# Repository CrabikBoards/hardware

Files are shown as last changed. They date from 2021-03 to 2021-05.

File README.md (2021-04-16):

# crabik

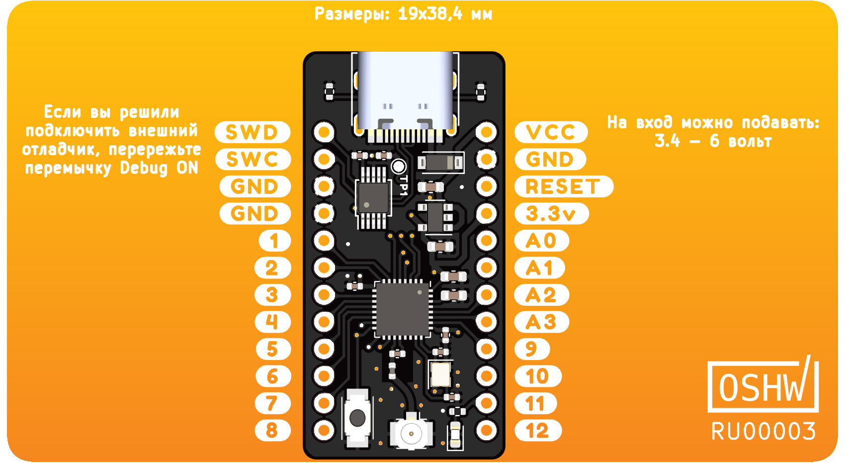
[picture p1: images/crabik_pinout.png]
crabik


Репозиторий с файлами дизайна платы для KiCad 5.1

| Вид сверху | Вид снизу |
|---|---|
| crabik_front | crabik_back |

## Описание

crabik это недорогая плата для изучения языка программирования [Rust](https://www.rust-lang.org/). Мозгом платы является микроконтроллер nRF52810. Плата имеет встроенный отладчик, основанный на CMSIS-DAP.

## Производство

Инструкция для заказа производства платы и монтажа на сервисе JLCPCB содержится в файле [PRODUCTION](PRODUCTION.md).

## Лицензия

Оборудование выпущено под лицензией CERN Open Hardware License v1.2. См. Файл [LICENSE](LICENSE) для получения дополнительной информации.

## Поддержка
Поддержите Амперку и оборудование с открытым исходным кодом, покупая продукты на [Amperka.ru](https://amperka.ru/)!

## Социальные сети Амперки

https://www.youtube.com/user/AmperkaRu

https://vk.com/amperkaru

https://www.instagram.com/amperkaru

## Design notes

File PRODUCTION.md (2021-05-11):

# Заказ производства

Загрузите дизайн из репозитория:
```
git clone git@github.com:CrabikBoards/hardware.git
```

В директории `production` находятся файлы BOM, позиций компонентов для монтажа, архив с GERBER файлами и файлами сверловки.

На сайте [jlcpcb.com](https://jlcpcb.com/) закажите печатные платы с монтажом.
Ниже показаны параметры заказа которые нужно выбрать, кол-во, цвет, толщина, и прочее выбирайте по своему желанию.

order settings 1

order settings 2

order settings 3

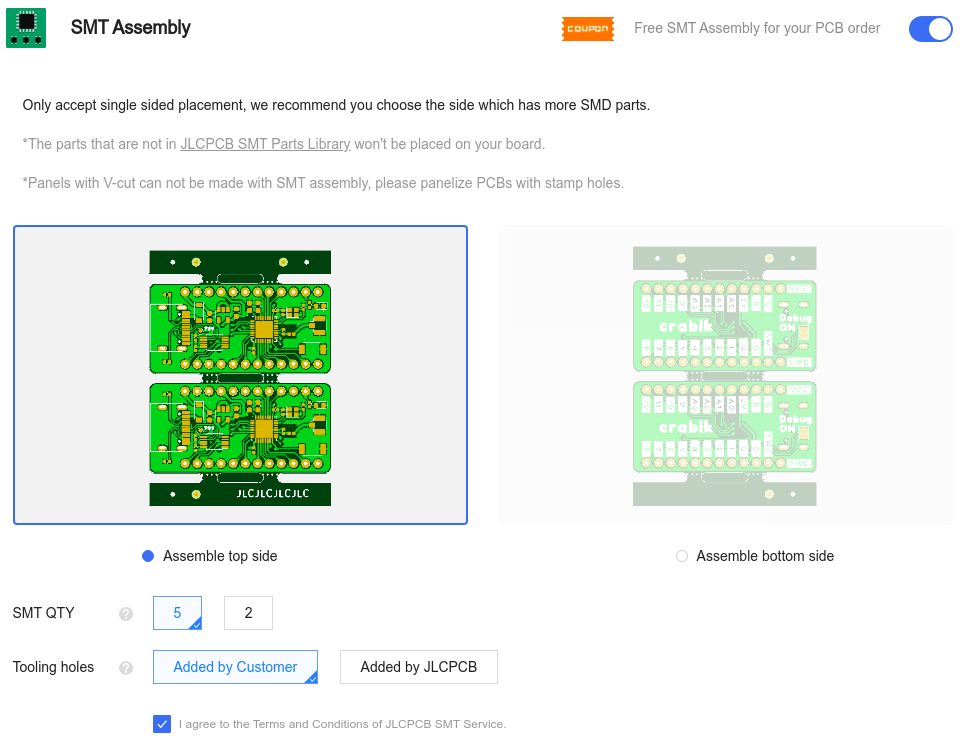
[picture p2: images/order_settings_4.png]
order settings 4


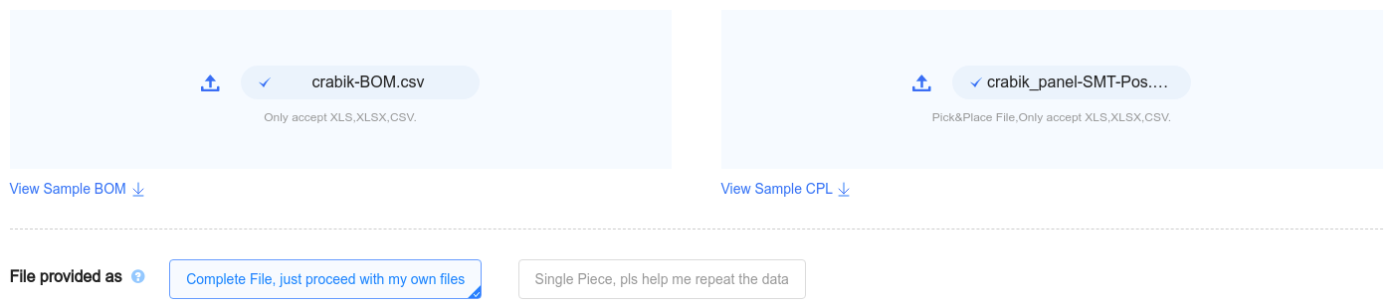
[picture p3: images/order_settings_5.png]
order settings 5


После получения и сборки платы, нужно прошить чип CH554 который выполняет роль CMSIS-DAP совместимого отладчика.

Установите Arduino IDE если она у вас не установлена и [добавте поддержку чипов CH55x](https://github.com/DeqingSun/ch55xduino#installation).

Загрузите Arduino проект из репозитория:
```
git clone git@github.com:CrabikBoards/debugger-firmware.git
```

Соедините контакт `TP1` с `VCC` через 20kOhm резистор, подключите плату к компьютеру и загрузите прошивку.

Все плата готова к работе!

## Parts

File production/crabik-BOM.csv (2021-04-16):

Comment | Designator | Footprint | LCSC Part #
U.FL-R-SMT-1 Generic connector, single row, 01x02, script generated (kicad-library-utils/schlib/autogen/connector/) | ANT1 | U.FL_Hirose_U.FL-R-SMT-1_Vertical | C88374
0.8pF Unpolarized capacitor, small symbol | C1 | C_0402_1005Metric | C326068
12pF Unpolarized capacitor, small symbol | C2,C3 | C_0402_1005Metric | C1547
100nF Unpolarized capacitor, small symbol | C4,C5,C9,C8 | C_0402_1005Metric | C1525
4.7uF Unpolarized capacitor, small symbol | C6 | C_0603_1608Metric | C8032
1uF Unpolarized capacitor, small symbol | C7,C11,C10 | C_0603_1608Metric | C1592
MBR0520 Schottky diode | D1 | D_SOD-123 | C475717
LED Light emitting diode | D2 | LED_0603_1608Metric | C2286
3.9nH Inductor | L1 | L_0402_1005Metric | C14033
USB-C USB 2.0-only Type-C Plug connector | P1 | TYPE-C16PIN | C393939
5.1K Resistor | R1,R2 | R_0402_1005Metric | C25905
1.5K Resistor | R3 | R_0402_1005Metric | C25867
Reset button Push button switch, generic, two pins | SW1 | TS-1088R-02526 | C455281
CH552E (or CH554E) | U1 | MSOP-10_3x3mm_P0.5mm | C111293
nRF52810-QCxx | U2 | QFN-32-1EP_5x5mm_P0.5mm_EP3.6x3.6mm | C519278
AP2112K-3.3 150mA low dropout linear regulator, wide input voltage range, 1.5V fixed positive output, SOT-23-5 | U3 | SOT-23-5 | C51118
32MHz Four pin crystal, GND on pins 2 and 4 | Y1 | Crystal_SMD_2016-4Pin_2.0x1.6mm | C254298

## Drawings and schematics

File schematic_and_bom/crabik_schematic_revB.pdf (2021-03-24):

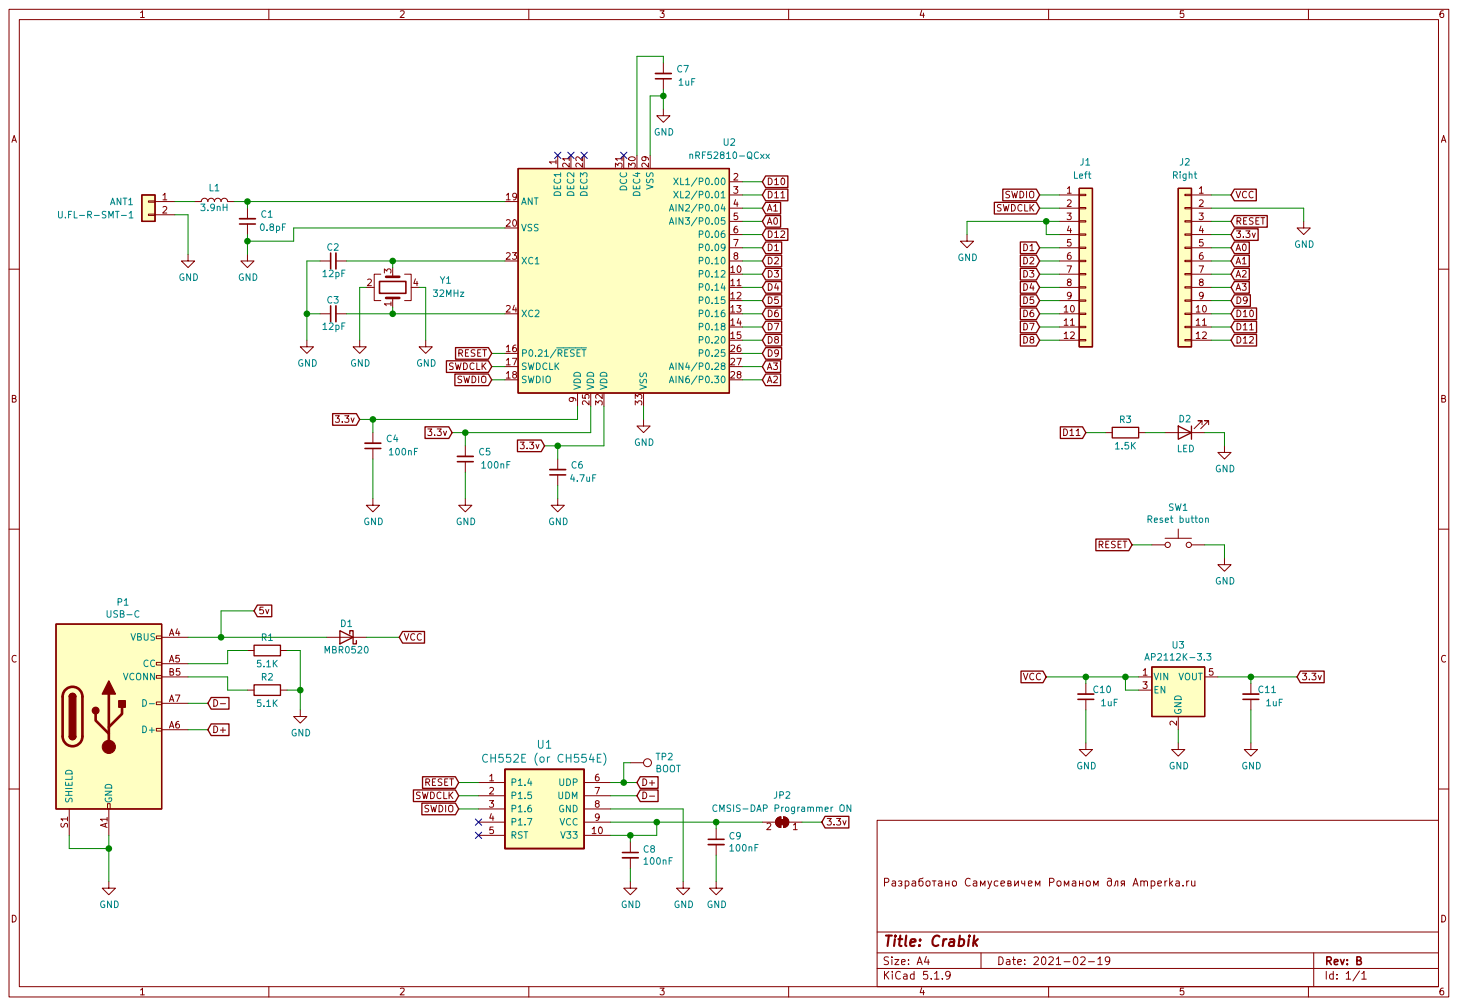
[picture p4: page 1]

1 P0.12 10 P0.14 11 P0.15 12 P0.16 13 P0.18 14 P0.20 15 P0.21/RESET 16 SWDCLK 17 SWDIO 18 ANT 19 XL1/P0.00 2 VSS 20 DEC2 21 DEC3 22 XC1 23 XC2 24 VDD 25 P0.25 26 AIN4/P0.28 27 AIN6/P0.30 28 VSS 29 XL2/P0.01 DEC4 3 30 DCC 31 VDD 32 VSS 33 AIN2/P0.04 4 AIN3/P0.05 5 P0.06 6 P0.09 7 P0.10 8 VDD

JP2 CMSIS-DAP Programmer ON

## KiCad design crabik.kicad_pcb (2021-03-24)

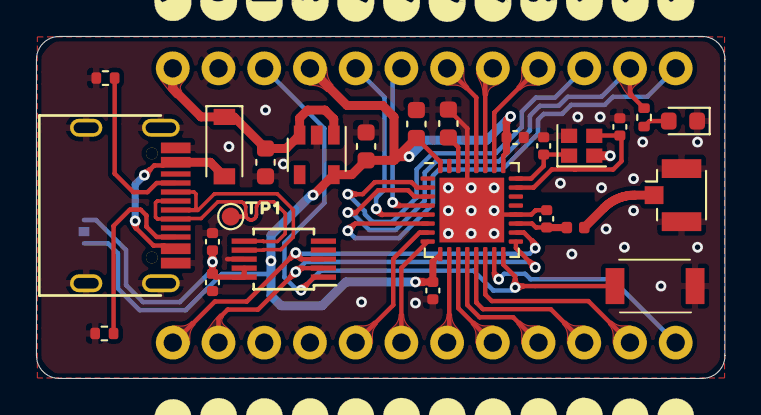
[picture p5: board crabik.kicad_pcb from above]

Board: 2 copper layers, 38.3 x 19.0 mm, 29 parts (1 on the bottom side), 34 nets.

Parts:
ANT1: U.FL-R-SMT-1; U.FL_Hirose_U.FL-R-SMT-1_Vertical
C1: 0.8pF; C_0402_1005Metric
C2, C3: 12pF; C_0402_1005Metric
C4, C5, C8, C9: 100nF; C_0402_1005Metric
C6: 4.7uF; C_0603_1608Metric
C7, C10, C11: 1uF; C_0603_1608Metric
D1: MBR0520; D_SOD-123
D2: LED; LED_0603_1608Metric
J1: Left; 1X12_NO_SILK
J2: Right; 1X12_NO_SILK
JP2: CMSIS-DAP Programmer ON; SolderJumper-2_P1.3mm_Bridged_Pad1.0x1.5mm
L1: 3.9nH; L_0402_1005Metric
OSHW_Mono_0.25_Scale: RU00003; OSHW_Mono_0.25_Scale
P1: USB-C; TYPE-C16PIN
R1, R2: 5.1K; R_0402_1005Metric
R3: 1.5K; R_0402_1005Metric
SW1: Reset button; TS-1088R-02526
TP2: BOOT; TestPoint_Pad_D1.0mm
U1: CH552E (or CH554E); MSOP-10_3x3mm_P0.5mm
U2: nRF52810-QCxx; QFN-32-1EP_5x5mm_P0.5mm_EP3.6x3.6mm
U3: AP2112K-3.3; SOT-23-5
Y1: 32MHz; Crystal_SMD_2016-4Pin_2.0x1.6mm

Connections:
3.3v: C4.2, C5.2, C6.2, C11.2, J2.4, JP2.1, U2.9, U2.25, U2.32, U3.5
5v: D1.2, P1.A4
A0: J2.5, U2.5
A1: J2.6, U2.4
A2: J2.7, U2.28
A3: J2.8, U2.27
D1: J1.5, U2.7
D2: J1.6, U2.8
D3: J1.7, U2.10
D4: J1.8, U2.11
D5: J1.9, U2.12
D6: J1.10, U2.13
D7: J1.11, U2.14
D8: J1.12, U2.15
D9: J2.9, U2.26
D10: J2.10, U2.2
D11: J2.11, R3.2, U2.3
D12: J2.12, U2.6
D+: P1.A6, TP2.1, U1.6
D-: P1.A7, U1.7
GND: ANT1.2, C1.1, C2.1, C3.1, C4.1, C5.1, C6.1, C7.1, C8.2, C9.2, C10.1, C11.1, D2.1, J1.3, J1.4, J2.2, P1.A1, P1.S1, R1.1, R2.1, SW1.2, U1.8, U2.20, U2.29, U2.33, U3.2, Y1.2, Y1.4
unnamed: ANT1.1, L1.1
unnamed: C1.2, L1.2, U2.19
unnamed: C2.2, U2.23, Y1.3
unnamed: C3.2, U2.24, Y1.1
unnamed: C7.2, U2.30
unnamed: C8.1, C9.1, JP2.2, U1.9, U1.10
unnamed: D2.2, R3.1
unnamed: P1.A5, R1.2
unnamed: P1.B5, R2.2
RESET: J2.3, SW1.1, U1.1, U2.16
SWDCLK: J1.2, U1.2, U2.17
SWDIO: J1.1, U1.3, U2.18
VCC: C10.2, D1.1, J2.1, U3.1, U3.3

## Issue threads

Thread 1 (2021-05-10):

Битые ссылки на crabik.ru

SomeoneToIgnore, 2021-05-10:
На https://crabik.ru/#/ есть две битые ссылки:

* ссылка на GitHub в правом верхнем углу ведёт на https://github.com/kekcheburec/crabik.ru
* ссылка "Купить crabik" ведёт на https://store/

Обе невалидны, было бы здорово убрать их или исправить ссылки в них.
Так же было бы здорово иметь возможность сообщать об ошибках на сайте более удобным способом.

kekcheburec, 2021-05-11:
Спасибо что обратили внимание на это.
Ссылка на репозитории сайта была не битая, сам репозитории был приватный, уже открыл его, все в порядке.
Кнопку для покупки я уберу, т.к. из-за проблем с компонентами у поставщика я занялся другими проектами. Купить плату нельзя, можно только самому заказать и допаять недостающие компоненты.

Closed 2021-05-11.

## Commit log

2021-03-24 Первый коммит (revB)
    [crabik.kicad_pcb, crabik.sch]
2021-03-25 Удаление лишнего
2021-04-16 Добавление информации и файлов для производства
2021-04-16 fix production directory
    [crabik-BOM.csv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]
2021-05-11 Добавление инструкций с прошивкой CH554 (в роли отладчика)
